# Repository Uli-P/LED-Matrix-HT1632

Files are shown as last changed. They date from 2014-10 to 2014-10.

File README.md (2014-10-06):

--- work in progress ---
<br>
PCB ordered today, 06.10.2014, at dirty pcbs
<br>
see http://dirtypcbs.com/view.php?share=2058&accesskey=2a689cab1304aab6307b2c241c448fc4
<br>
This is hardware for a HT1632C LED matrix driver, an optional driver and a common cathode or common anode led 60x60mm led matrix.<br>
SJ1 - according to the datasheet you can connect the chip's OSP pin either to GND or VCCIO, don't know for what it's good<br>
SJ2 - connect to VCCIO if you drive the logic side from separate power, else to VCC<br>
SJ3 - connect to VCC if you have a common anode matrix, to GND if common cathode<br>

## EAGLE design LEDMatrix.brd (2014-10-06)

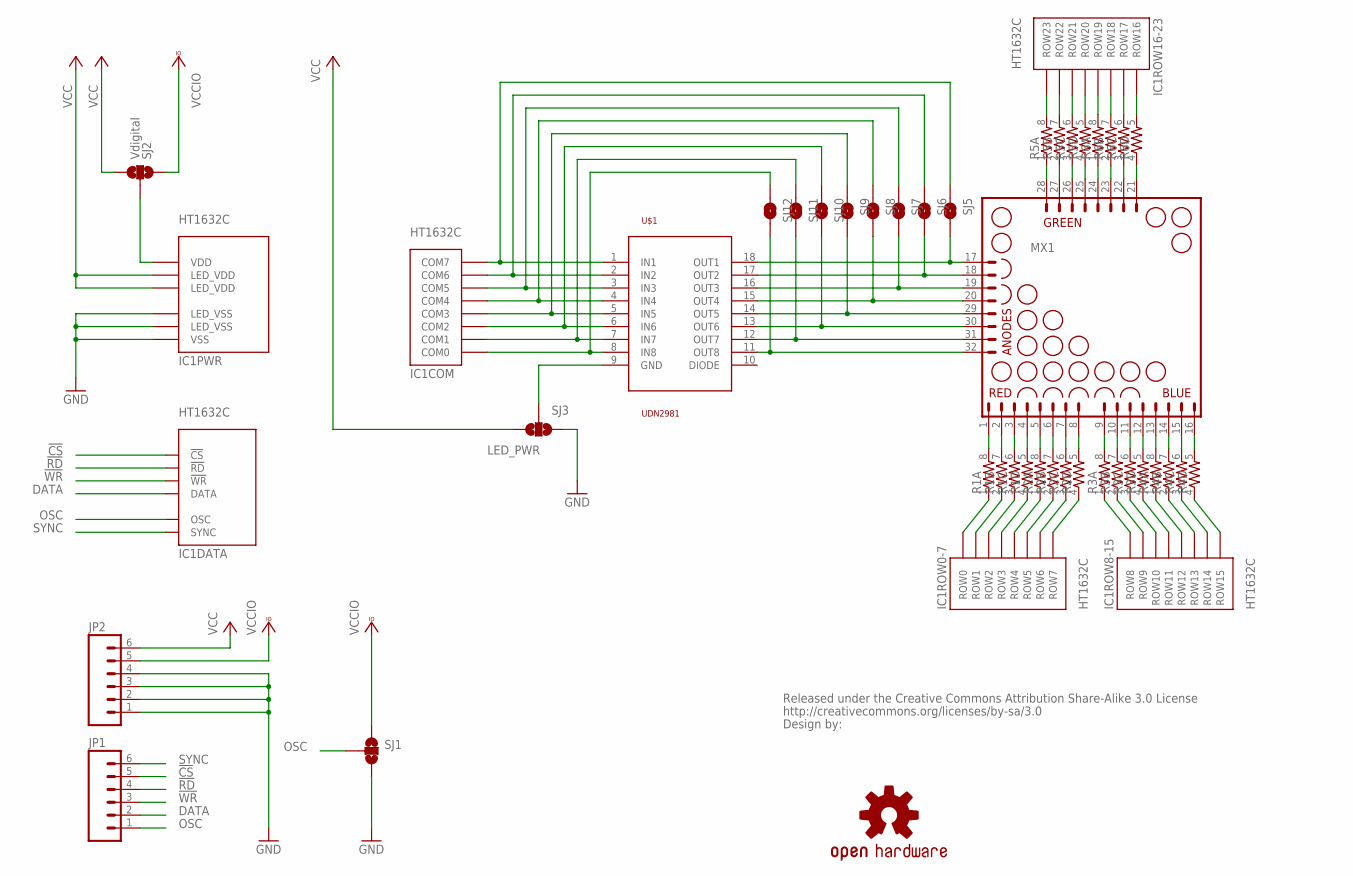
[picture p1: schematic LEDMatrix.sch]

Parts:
CC_TEXT1: CREATIVE_COMMONS
IC1: HT1632C; QFP52
JP1, JP2: M06SIP; 1X06
LOGO1: OSHW-LOGOL; OSHW-LOGO-L
MX1: MATRIX_8X8_TRICOLOR_ANODE_ROW; MATRIX_60MM_32PIN
R1, R2, R3, R4, R5, R6: RESISTOR-ARRAY0603-ARV; 0603-ARV
SJ1: SOLDERJUMPER_2WAY-OLDS; SJ_3
SJ2: Vdigital; SJ_3
SJ3: LED_PWR; SJ_3
SJ5, SJ6, SJ7, SJ8, SJ9, SJ10, SJ11, SJ12: SOLDERJUMPER-OLDNO; SJ_2S-NO
U$1: UDN2981; SO18L

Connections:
!CS: IC1.P$19 (!CS), JP1.5
!RD: IC1.P$18 (!RD), JP1.4
!WR: IC1.P$17 (!WR), JP1.3
COM0: IC1.P$22 (COM0), SJ12.1, U$1.8 (IN8)
COM1: IC1.P$23 (COM1), SJ11.1, U$1.7 (IN7)
COM2: IC1.P$24 (COM2), SJ10.1, U$1.6 (IN6)
COM3: IC1.P$26 (COM3), SJ9.1, U$1.5 (IN5)
COM4: IC1.P$27 (COM4), SJ8.1, U$1.4 (IN4)
COM5: IC1.P$28 (COM5), SJ7.1, U$1.3 (IN3)
COM6: IC1.P$29 (COM6), SJ6.1, U$1.2 (IN2)
COM7: IC1.P$30 (COM7), SJ5.1, U$1.1 (IN1)
DATA: IC1.P$16 (DATA), JP1.2
GND: IC1.P$14 (VSS), IC1.P$25 (LED_VSS), IC1.P$36 (LED_VSS), JP2.1, JP2.2, JP2.3, JP2.4, SJ1.3, SJ3.1
unnamed: MX1.32, SJ12.2, U$1.11 (OUT8)
unnamed: MX1.31, SJ11.2, U$1.12 (OUT7)
unnamed: MX1.30, SJ10.2, U$1.13 (OUT6)
unnamed: MX1.29, SJ9.2, U$1.14 (OUT5)
unnamed: MX1.20, SJ8.2, U$1.15 (OUT4)
unnamed: MX1.19, SJ7.2, U$1.16 (OUT3)
unnamed: MX1.18, SJ6.2, U$1.17 (OUT2)
unnamed: MX1.17, SJ5.2, U$1.18 (OUT1)
unnamed: IC1.P$21 (VDD), SJ2.2
unnamed: MX1.1, R1.8 (2)
unnamed: MX1.2, R1.7 (2)
unnamed: MX1.3, R1.6 (2)
unnamed: MX1.4, R1.5 (2)
unnamed: MX1.5, R2.8 (2)
unnamed: MX1.6, R2.7 (2)
unnamed: MX1.7, R2.6 (2)
unnamed: MX1.8, R2.5 (2)
unnamed: MX1.9, R3.8 (2)
unnamed: MX1.10, R3.7 (2)
unnamed: MX1.11, R3.6 (2)
unnamed: MX1.12, R3.5 (2)
unnamed: MX1.13, R4.8 (2)
unnamed: MX1.14, R4.7 (2)
unnamed: MX1.15, R4.6 (2)
unnamed: MX1.16, R4.5 (2)
unnamed: MX1.28, R5.1
unnamed: MX1.27, R5.2 (1)
unnamed: MX1.26, R5.3 (1)
unnamed: MX1.25, R5.4 (1)
unnamed: MX1.24, R6.1
unnamed: MX1.23, R6.2 (1)
unnamed: MX1.22, R6.3 (1)
unnamed: MX1.21, R6.4 (1)
OSC: IC1.P$15 (OSC), JP1.1, SJ1.2
ROW0: IC1.P$13 (ROW0), R1.1
ROW1: IC1.P$12 (ROW1), R1.2 (1)
ROW2: IC1.P$11 (ROW2), R1.3 (1)
ROW3: IC1.P$10 (ROW3), R1.4 (1)
ROW4: IC1.P$9 (ROW4), R2.1
ROW5: IC1.P$8 (ROW5), R2.2 (1)
ROW6: IC1.P$6 (ROW6), R2.3 (1)
ROW7: IC1.P$5 (ROW7), R2.4 (1)
ROW8: IC1.P$4 (ROW8), R3.1
ROW9: IC1.P$3 (ROW9), R3.2 (1)
ROW10: IC1.P$2 (ROW10), R3.3 (1)
ROW11: IC1.P$1 (ROW11), R3.4 (1)
ROW12: IC1.P$52 (ROW12), R4.1
ROW13: IC1.P$51 (ROW13), R4.2 (1)
ROW14: IC1.P$50 (ROW14), R4.3 (1)
ROW15: IC1.P$49 (ROW15), R4.4 (1)
ROW16: IC1.P$48 (ROW16), R6.5 (2)
ROW17: IC1.P$47 (ROW17), R6.6 (2)
ROW18: IC1.P$46 (ROW18), R6.7 (2)
ROW19: IC1.P$45 (ROW19), R6.8 (2)
ROW20: IC1.P$44 (ROW20), R5.5 (2)
ROW21: IC1.P$43 (ROW21), R5.6 (2)
ROW22: IC1.P$42 (ROW22), R5.7 (2)
ROW23: IC1.P$41 (ROW23), R5.8 (2)
SYNC: IC1.P$20 (SYNC), JP1.6
VCC: IC1.P$7 (LED_VDD), IC1.P$38 (LED_VDD), JP2.6, SJ2.3, SJ3.3
VCCIO: JP2.5, SJ1.1, SJ2.1
VLED: SJ3.2, U$1.9 (GND)

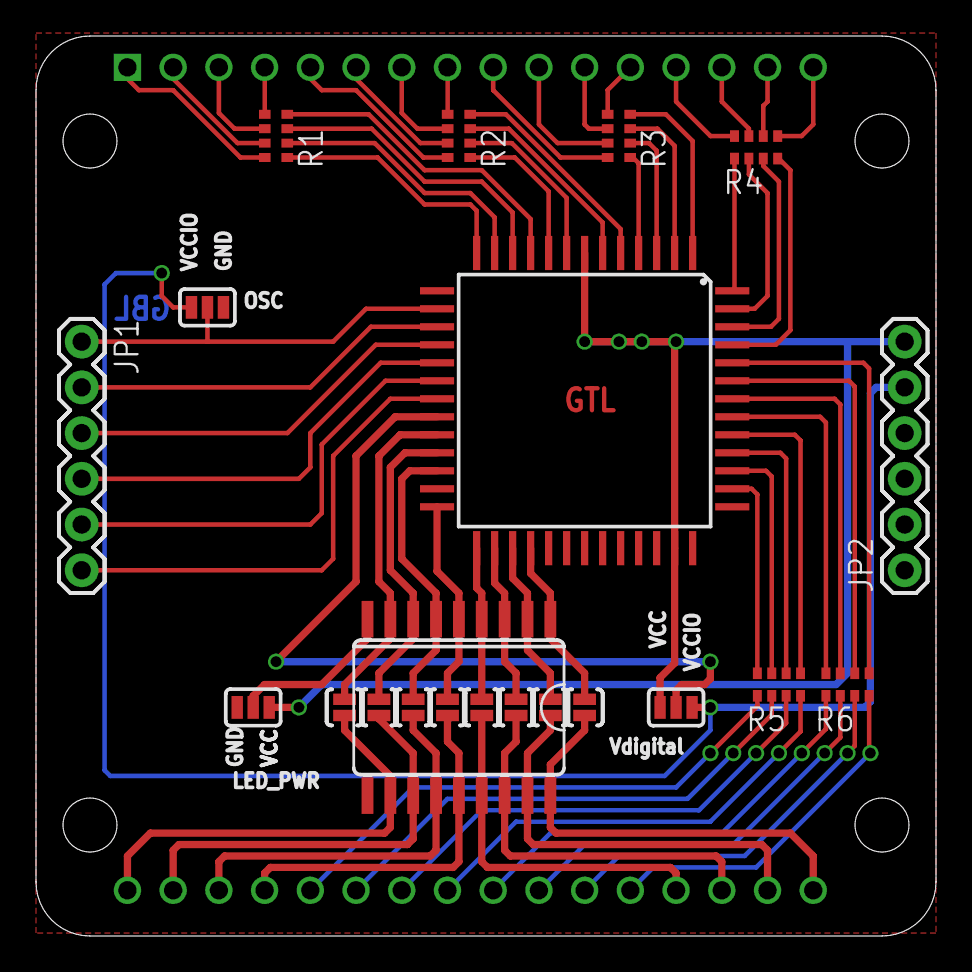
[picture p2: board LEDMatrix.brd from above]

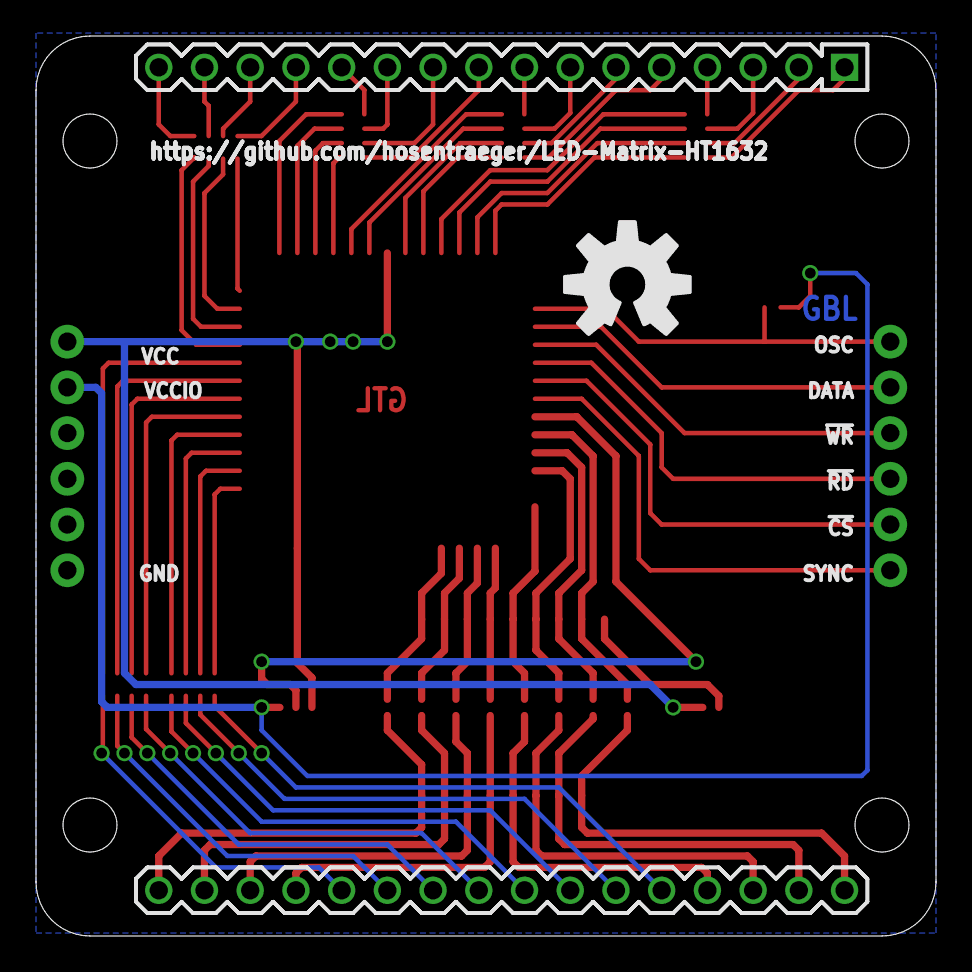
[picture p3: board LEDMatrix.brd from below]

Board: 2 copper layers, 50.0 x 50.0 mm, 24 parts (2 on the bottom side), 75 nets.

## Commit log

2014-09-27 updated silk layer
    [LEDMatrix.brd, LEDMatrix.sch]
2014-10-06 added reference to dirty pcbs
2014-10-06 replaced parts library (schematic only)
    [LEDMatrix.brd, LEDMatrix.sch]

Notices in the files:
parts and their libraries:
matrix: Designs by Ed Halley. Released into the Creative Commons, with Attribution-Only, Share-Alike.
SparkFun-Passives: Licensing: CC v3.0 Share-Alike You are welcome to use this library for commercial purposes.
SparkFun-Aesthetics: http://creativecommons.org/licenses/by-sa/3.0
